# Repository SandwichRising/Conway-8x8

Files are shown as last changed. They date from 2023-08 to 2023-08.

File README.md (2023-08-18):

# Conway-8x8
8x8 Circuit Sculpture of Conway's Game of Life
conway front Conway Circuit Sculpture
conway back Conway Circuit Sculpture Backside
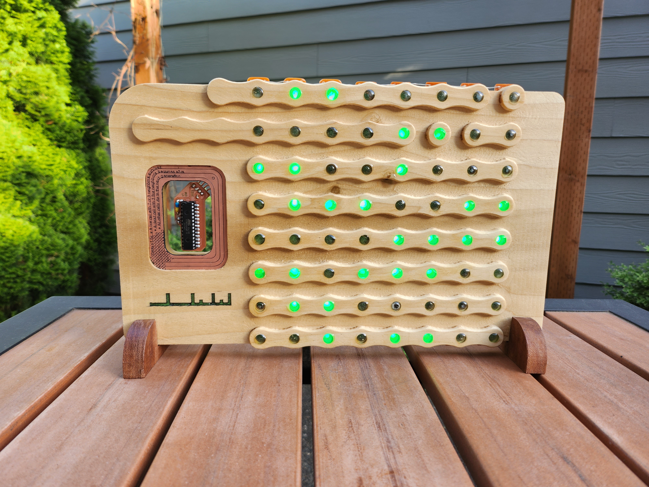
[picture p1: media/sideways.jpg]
conway sideways Conway Circuit Sculpture Sideways


   This project is the collection of files necessary to make the above pictured 8x8 grid sculpture playing out [Conway's Game of Life](https://www.youtube.com/watch?v=Kk2MH9O4pXY) on an ATmega 328P. This project spanned 3 separate periods: 110 hours were spent developing the original software and building a circuit sculpture for a [separate 6x6 design](./media/6x6_design.jpg) which maxed the CPU capabilities; 20 hours were spent doing a technical analysis, refactoring, and writeup of the created data structure to scale from 6x6 to larger sizes; 130 hours over 3 weeks were then spent developing this project into new physical hardware. 

   The 130-hour period is captured in this github. This time was spent integrating the new 8x8 software to match new hardware, conceptualizing the full physical design from scratch, modeling the wooden case in Fusion360, designing the circuit boards in KiCad, producing CNC gcode for the PCBs and case in Fusion360, cutting the wood and copper/fr4 circuit boards on an Onefinity CNC machine, treating the wood and creating epoxy lenses, soldering the circuits, as well as testing and improving the design while in-progress. The project was created to demonstrate hardware implementation of a data structure (from concept to physical object) for a classroom grade, as this process is much more complicated than a solely-software approach. Unfortunately, the project did not count for very much credit, however the entire process was quite therapeutic and educational, and I was very pleased with the results.

## What the Sculpture Does
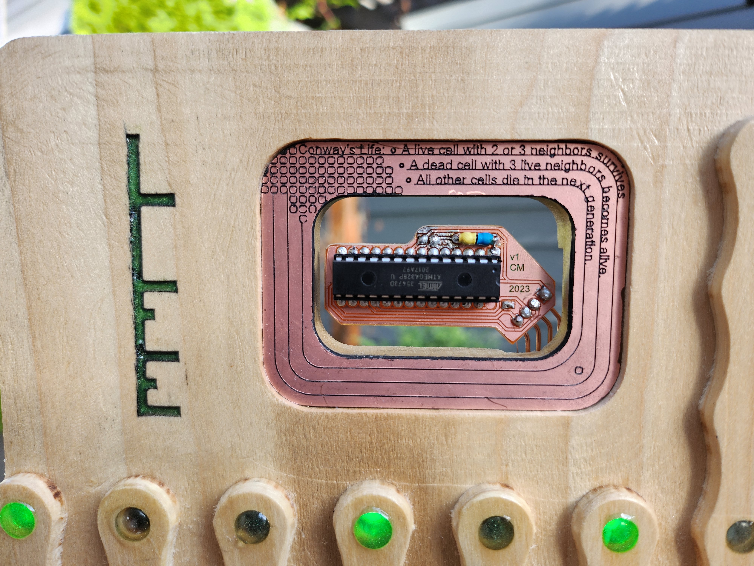
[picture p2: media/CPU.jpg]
brain PCB ATmega 328P CPU

   The sculpture creates a random gameboard using a floating microcontroller pin, and then applies Conway’s rules to evolve which cells live or die. The floating pin polls random energy in the air to seed the random number generator. The gameboard itself represents viewing one of an infinitely repeating 8x8 grid in every direction, as the top/bottom and left/right sides are considered ‘touching’ for the evolution process. Another way to visualize this is as a grid stretched over a [torus](https://en.wikipedia.org/wiki/Torus). This implementation remembers 48 board histories to check for duplicates, as a duplicate gameboard will always evolve along the same path (which traps the display into repeating itself forever). The bulk of the processor’s memory is used in saving these histories. If a duplicate gameboard is detected in history, the living cells flash out of existence in a specific way to let the observer know they ‘lived forever’, and a new random gameboard is generated. Otherwise, the game will continue to play out until all cells die out, and afterward a new board is generated. This 8x8 board has 68,719,476,736 unique starting conditions possible. 
  
  You can see the sculpture running in the video below. Unfortunately, the camera shutter speed clashes a bit with the FPS of the sculpture so the video footage doesn’t look as good as seeing it run in person. Lopsided ‘blinky’ math is used to transition cells on and off to make it easier for one's brain to track the groups of cells dying and coming alive each evolution cycle. The video was recorded while testing that the sculpture display matched what the software was providing, with an external Arduino streaming data to the display and the laptop simultaneously.
running display Display Running Test Program

   I enjoy seeing the display run from behind the sculpture, where the LEDs can be seen through the circuit boards.
running display from behind Display Running Viewed From Behind

## The Project’s Goals
   The intent of the project had two primary purposes: refactor the existing software data structure to be more efficient, and to develop new improved techniques for hardware creation to realize the data structure physically. In software, a technical analysis of the original 6x6 data structure was done and improvements were made to allow up to a 32x32 size (while still maintaining auto-reset features to detect if a repeating pattern emerged). Methods for further improvement were also discovered, but not yet implemented. After the software was improved, an 8x8 size for the hardware was chosen for timeline practicality. In hardware, the goals were to create working SMD circuits using a CNC process, integrating multiple of these PCBs together into a larger overall circuit, designing this circuit alongside a tailor-cut housing to host them, and to attempt using epoxy as an appealing LED lens.
   
   The software was developed in Arduino IDE v1.8.13. [The source code is provided here](./src/conway3/conway3.ino).

## The Build Log
  The rest of this readme is designed as a build log. The build process is documented below for anyone wishing to recreate this sculpture. STL files for all housing pieces are located [here](./models), KiCad files for the circuit are provided [here](./kicad/conway), and images of the different PCB traces for an etching process are provided [here](./pcb_svg_images). Creating/providing gcode is outside the scope of this writeup, as the process is highly dependent on the specific tools used to manufacture.
  
   The housing is made from poplar wood, a light wood with a subtle natural greenish tint. The feet (and failed trim) are made from sapele, a naturally red wood. The wood and PCBs were all sealed with a polyurethane spray for protection. The circuits are all cut from single-sided copper fr4 PCB blanks. The CPU is a standalone ATmega 328P (flashed as a standalone chip using it's internal oscillator), 10k resistor (with yellow/blue shrink, to pull the reset pin up to 5v), and 10uF capacitor (seen on the rear, required for power smoothing). The LED PCBs use [74HC595 shift registers]( https://www.digikey.com/en/products/detail/nexperia-usa-inc/74HC595D-118/763087), [470 Ohm resistor arrays](https://www.digikey.com/en/products/detail/bourns-inc/CAY16-471J4LF/2566756), and generic green 3V 20mA LEDs. A generic USB PCB was soldered to the GND and 5V lines of the bus PCB (the 328P chip used does not support USB data, so only power was connected).

After developing the software, the circuits were drawn in KiCad (v5.1.9) to find the practical sizes and shapes for the circuit boards.
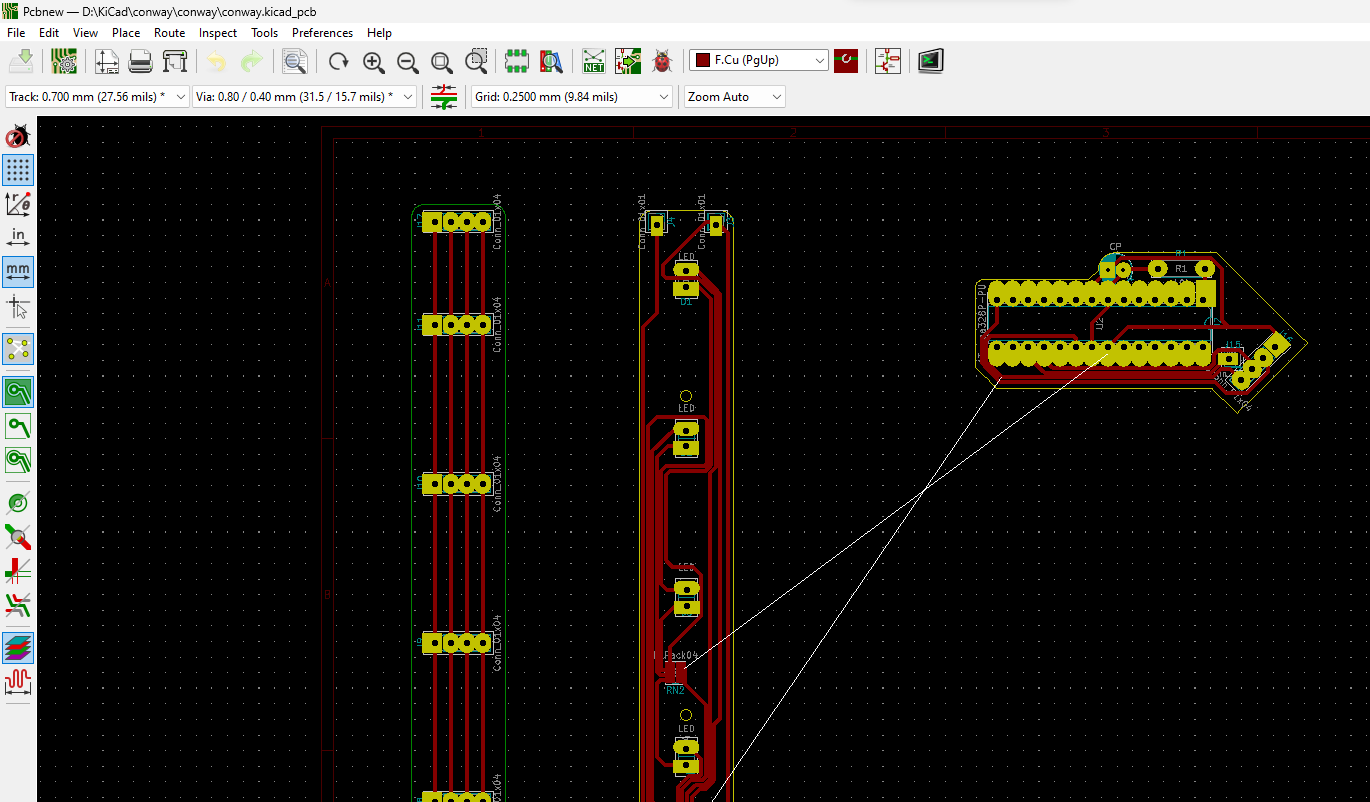
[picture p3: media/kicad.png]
kicad KiCad desktop view


Once the circuits were designed and sized, electronic components were ordered and the wooden housing was modeled in Fusion360. After modeling, machine cutpaths were assigned and exported as gcode in Fusion360 and the back of the housing was cut. Wooden pillars were used to place the wood stock precisely on the CNC bed, as the board would need flipped on the next step, and the pillars allowed for exact X and Y axis alignment. Before cutting, a small amount of polyurethane was sprayed where the text engraving would be to prevent paint overspray from absorbing into the wood. After cutting, this engraving area was taped off and sprayed with black spray paint. After drying, sanding the area removed the excess paint but left the engraved text painted.
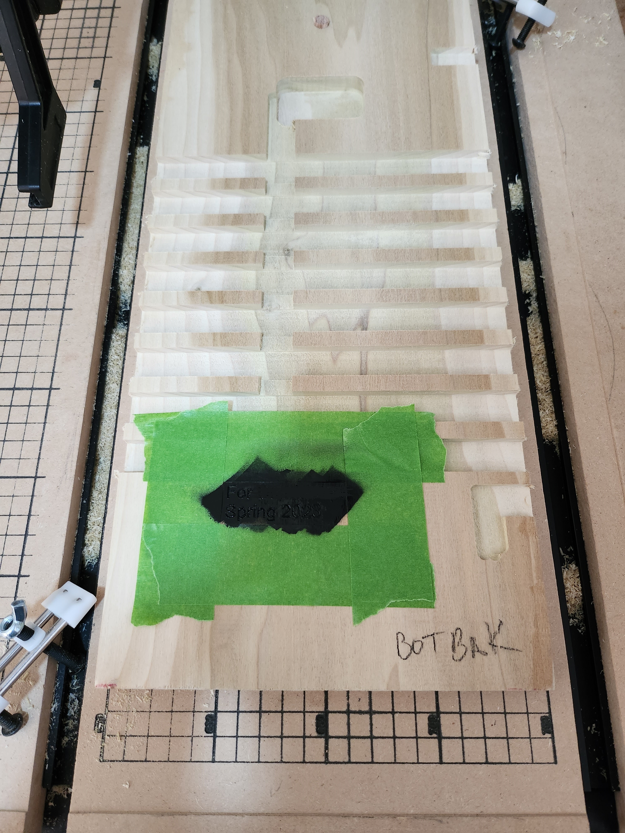
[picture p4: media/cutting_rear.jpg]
cutting rear housing Cutting Rear Housing


The wooden board was then flipped, aligned to the bed’s peg holes, and the front was then cut. The front used different woodworking bits to create the wavy pattern, cut away bulk material, engrave lettering, and drill LED holes. The same spray paint technique from before was used to fill the LIFE lettering with black paint (green epoxy was added later).
front housing Cutting Waves
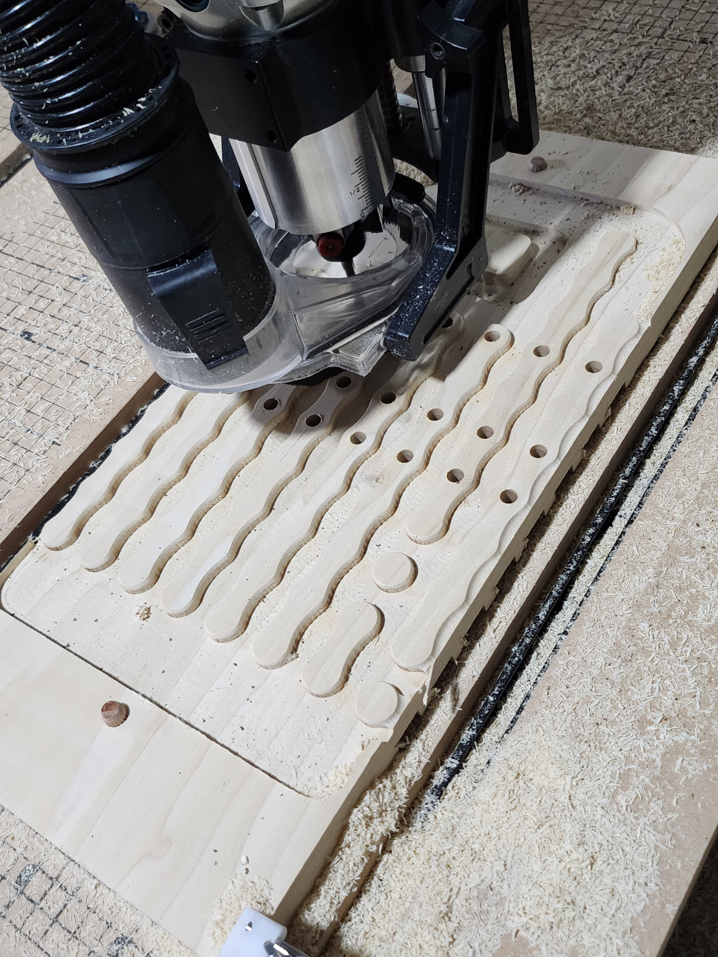
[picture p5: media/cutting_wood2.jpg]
front housing Cutting Holes

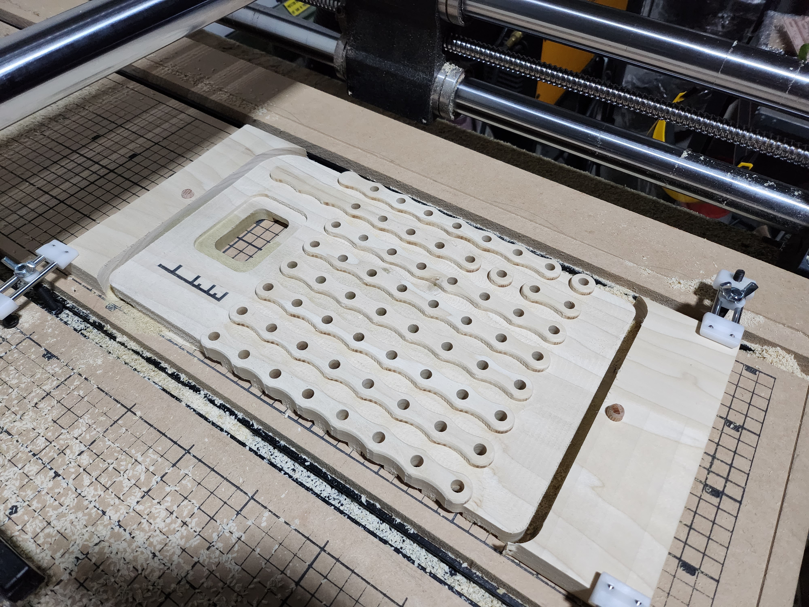
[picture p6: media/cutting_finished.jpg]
front housing Finished Cutting


A process with two different types of epoxy was used for the visibile lenses over the leds. First, clear tape was placed over the display face, covering the LED holes, and a small amount of 2-part green epoxy was poured into the holes from behind. After the epoxy had time to set, the tape was removed and a different UV epoxy was added in a droplet-shape to create a magnifying lens over the top, then hardened with a UV light into its round shape. This picture shows the piece of scrap wood to test the process. Only one of the 5 test pours pictured has the UV lens over the top.
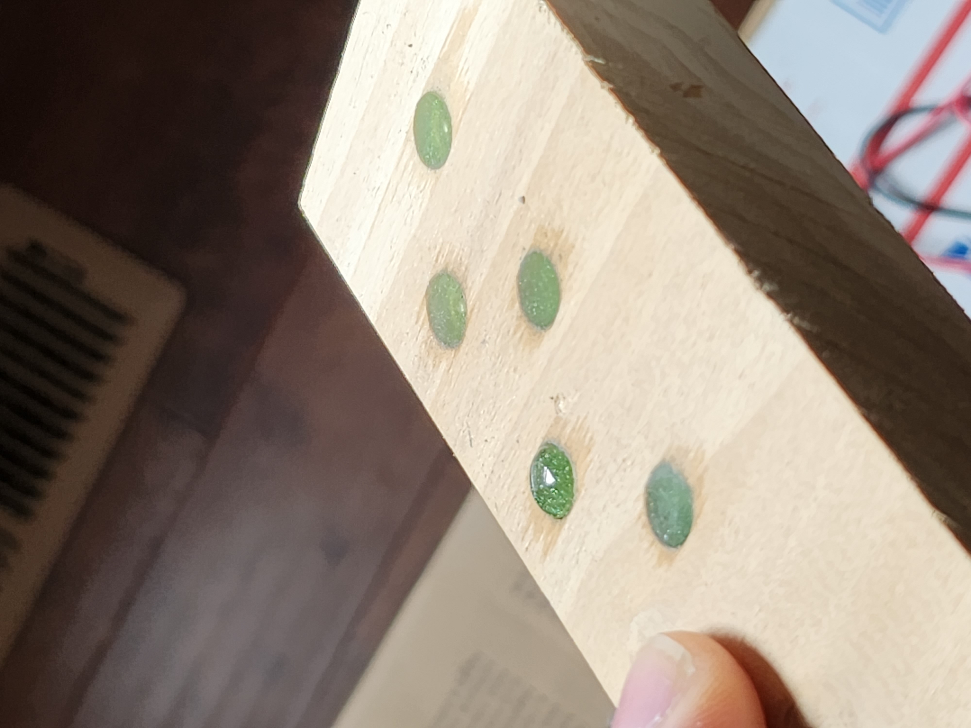
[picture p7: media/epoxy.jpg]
testing epoxy Epoxy Test


Additional trim was modeled and cut, with the plan to have more contrast in the design.
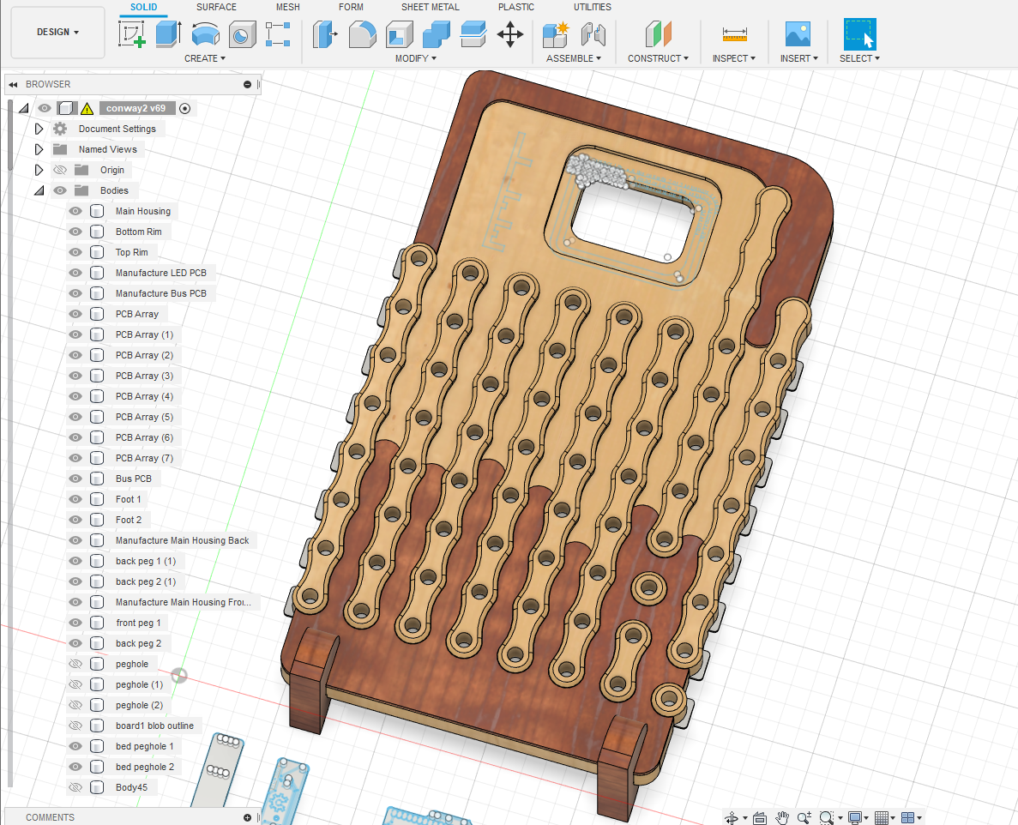
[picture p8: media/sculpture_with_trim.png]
trim design Trim Design

This did not work out as planned, though. The trim wood was cut to only be 3mm thick, but the board used was not perfectly flat and this resulted in a failed cut. Pre-processing the side of the board resting against the CNC machine bed flatter with a surfacing bit could have prevented this. There wasn’t enough sapele left in my shop to try again, so the contrasting trim idea was scrapped along with the failed cuts.  
trim failure Failed Trim Cut

Luckily, the section of sapele reserved for the feet was still usable, and this cut went well.
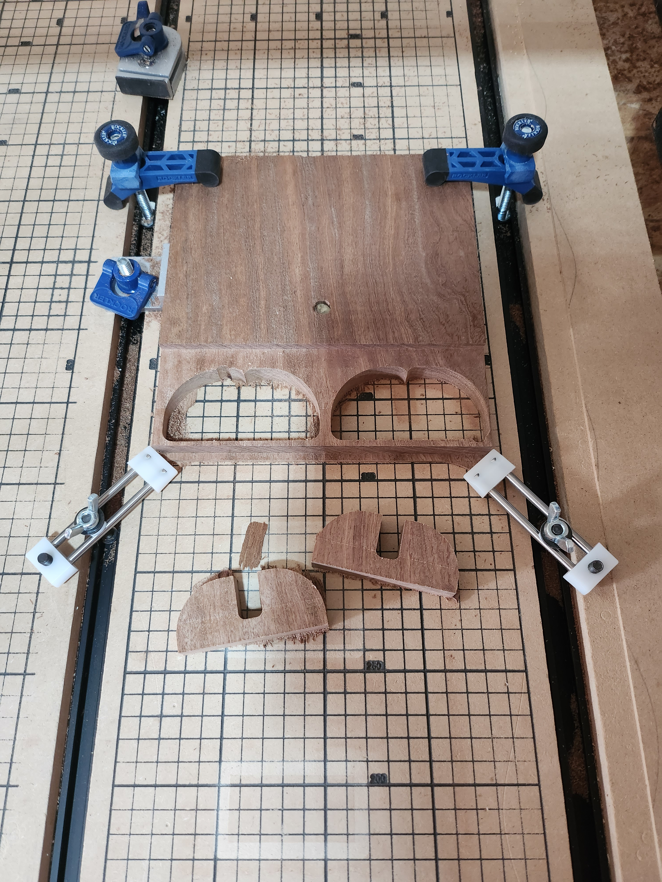
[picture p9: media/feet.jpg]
feet cutting Feet Cut


The LED PCBs were then cut on the CNC machine. The electrical traces are 0.7mm wide, and I had not cut this finely before. A total of 4 different styles of bits were used over multiple days before finding a 60-degree (inclusive) carbide bit that cut well at around 10k RPM, with some of the finer angled bits breaking in the process. More than 15 PCBs were cut, with 8 being usable in the end. You can see some of the progress from right to left in the picture.
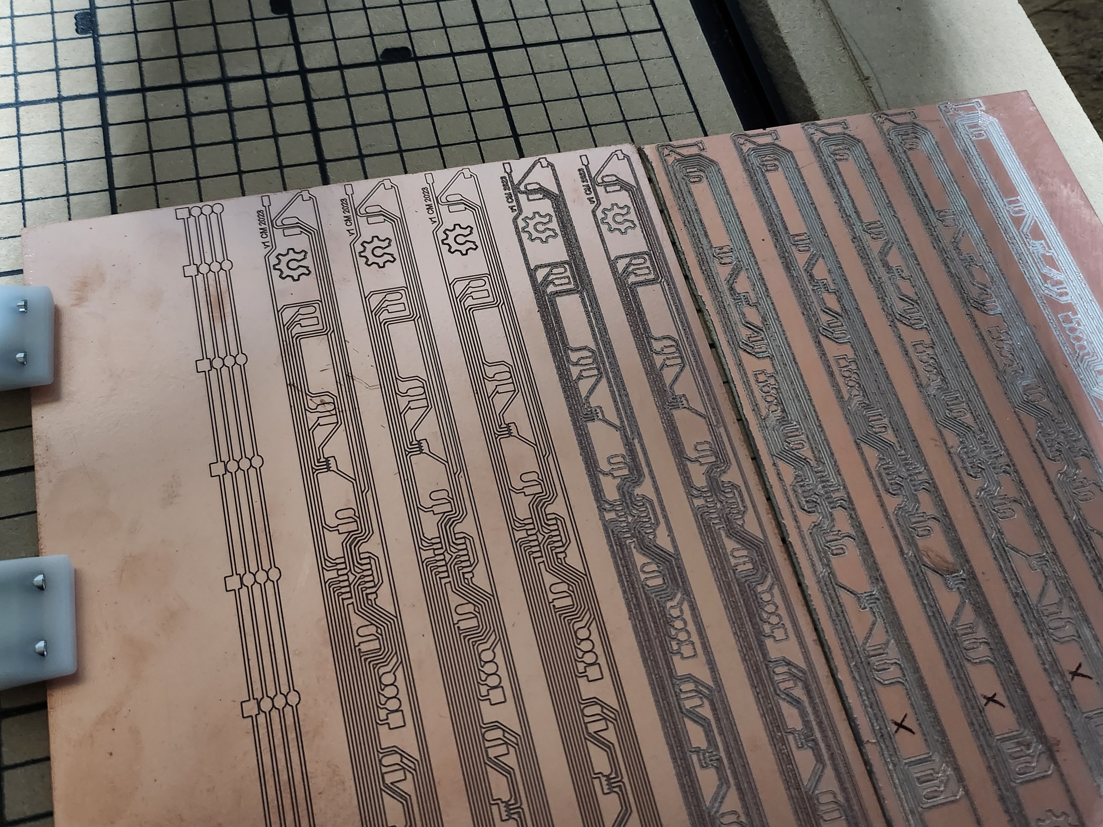
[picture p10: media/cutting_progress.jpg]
led pcb cuts LED PCB Cutting Progress


Each PCB was hand soldered using a syringe of lead-free low temperature solder on the SMD parts, and lead-free spooled solder on the through-hole parts. The soldering was done with a combination of hot air reflow and soldering iron work until all connections tested correctly with a multimeter. 
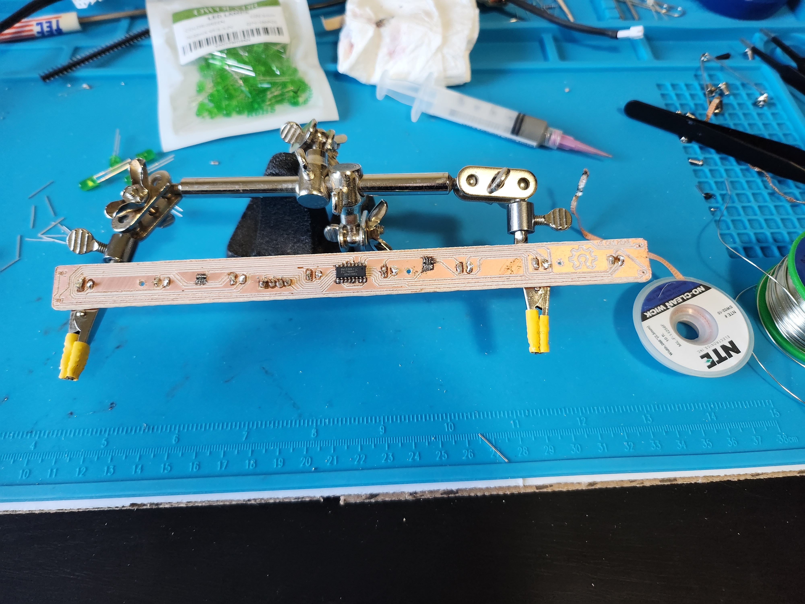
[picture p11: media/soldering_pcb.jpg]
led pcb soldering LED PCB Soldering


The LED PCBs were then assembled using the bus PCB to connect them all, and then brain PCB was attached using solid-core wire (to create a floating effect) and a thin data wire was run to the data-in of the first LED PCB. All the data-out/data-in ports on the LED PCBs were then connected using solid core wire along the side of the structure. The USB port was also connected to the bus PCB, but only 5v and GND were connected to the USB port. 
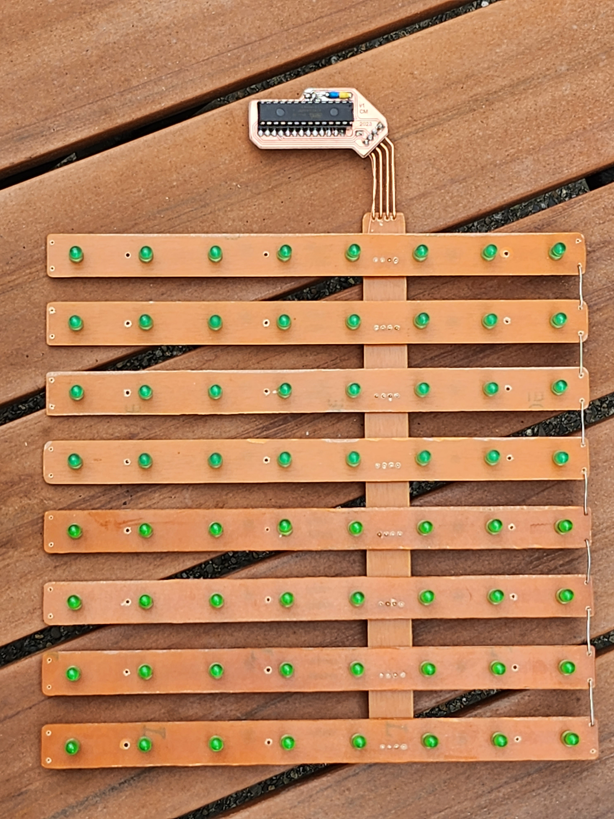
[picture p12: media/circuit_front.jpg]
completed circuit Complete Circuit

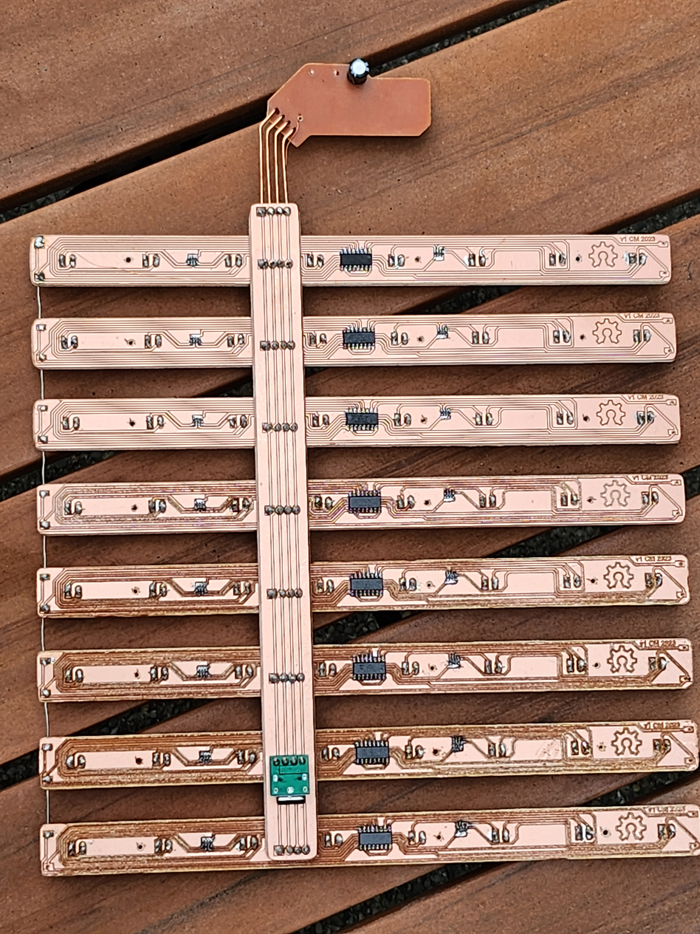
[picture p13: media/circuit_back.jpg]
completed circuit from behind Complete Circuit Back


The display was tested during assembly by streaming data from an Arduino UNO (with a 328P processor) using jumper wires, making sure the display matched up with what the software was outputting to the laptop over serial connection (shown in a video above). After the testing was verified and the circuit was fully assembled, the copper was sprayed with polyurethane to protect it from moisture.
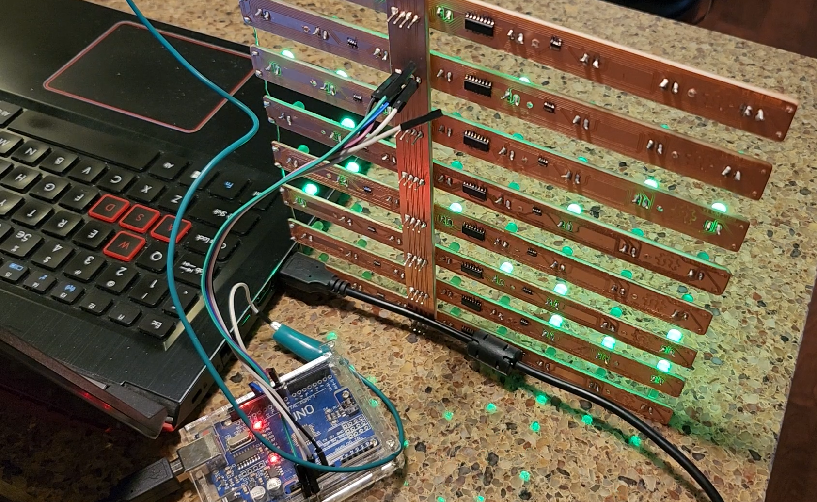
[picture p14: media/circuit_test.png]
testing the circuit Testing the Full Display


After all testing was done, a standalone 328P was flashed with the 8x8 program (using the internal oscillator instead of external clock) and the circuit was attached to the housing with screws. The view from the rear while its running is still my favorite.
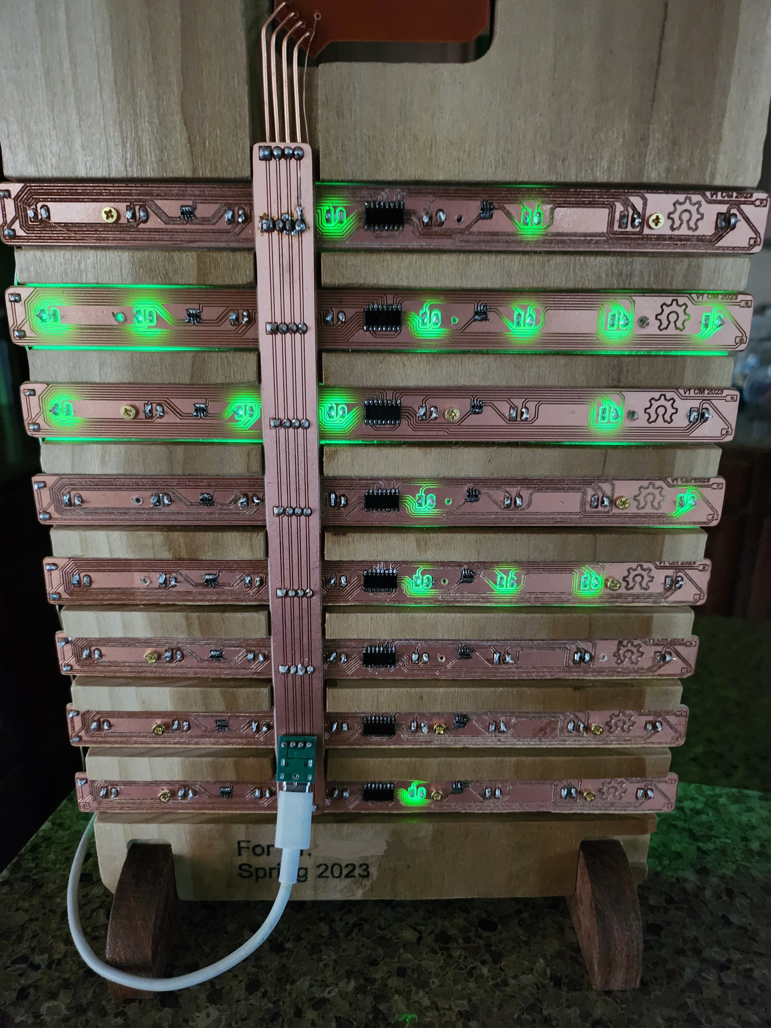
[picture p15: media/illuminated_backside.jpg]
circuit running and viewed from behind Viewing the Display from Behind


If you’ve made it this far, extra thanks for taking a look! If you make one, be sure to let me know!

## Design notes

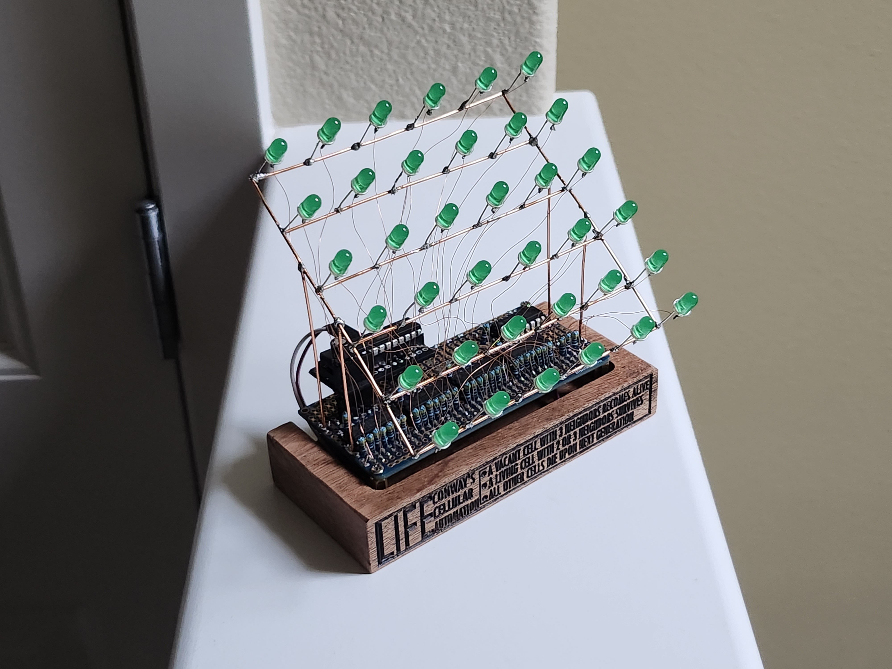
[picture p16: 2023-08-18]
media/6x6_design.jpg

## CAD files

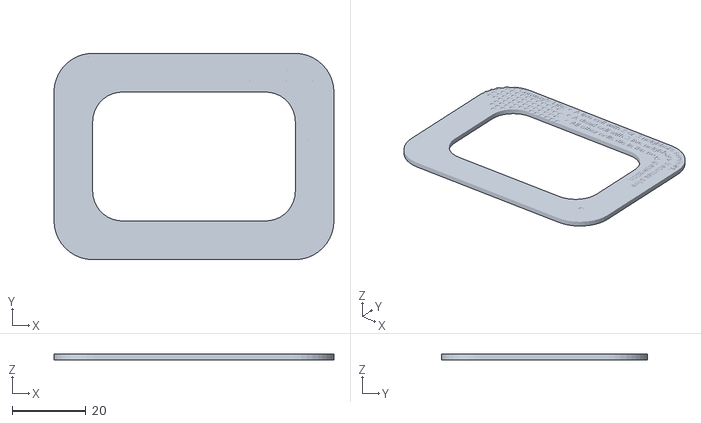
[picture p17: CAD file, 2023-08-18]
models/conway-8x8_decorative_plate.stl
76.0 x 56.0 x 1.50

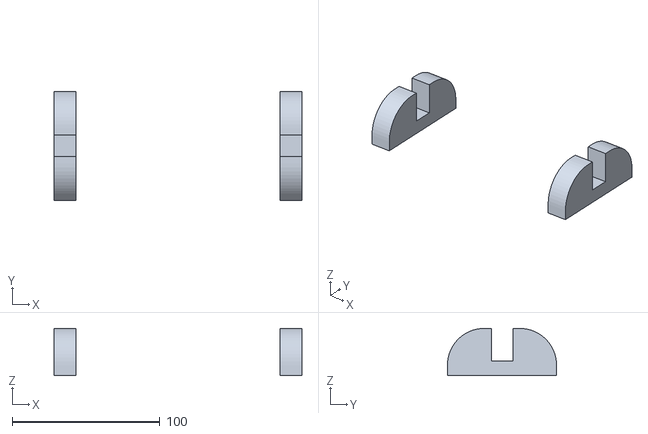
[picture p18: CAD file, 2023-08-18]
models/conway-8x8_feet.stl
168.0 x 74.0 x 32.0

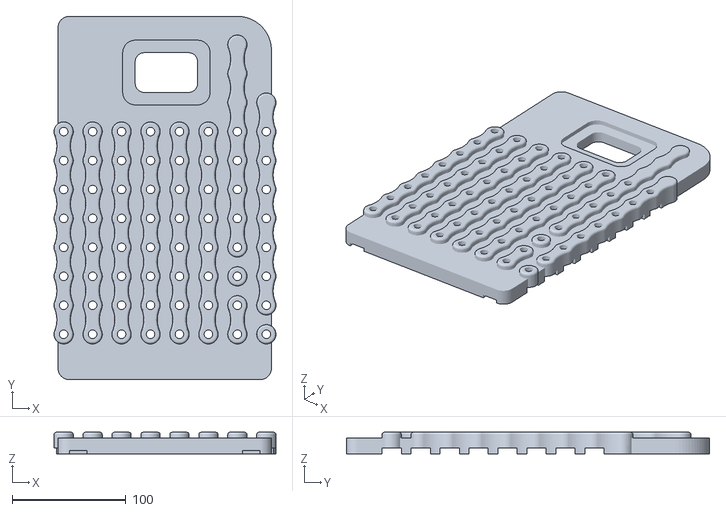
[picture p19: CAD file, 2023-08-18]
models/conway-8x8_housing.stl
195.5 x 320.0 x 19.0

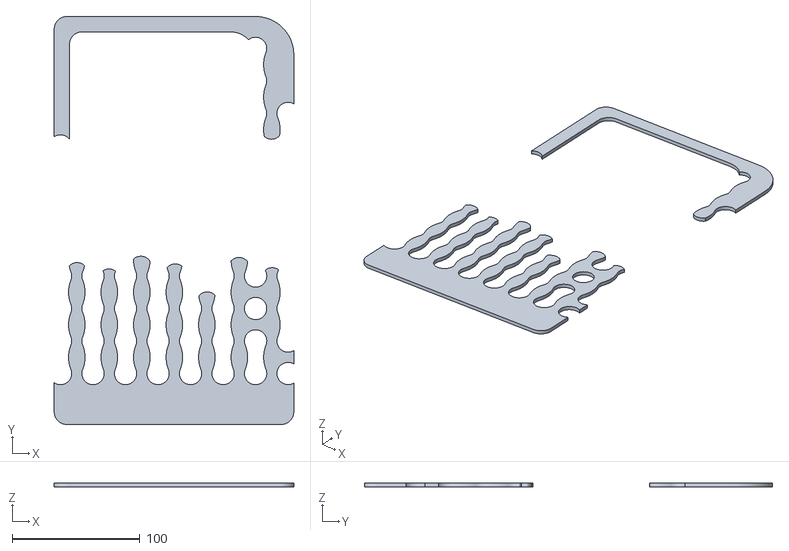
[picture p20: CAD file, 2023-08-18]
models/conway-8x8_decorative_trim.stl
188.0 x 320.0 x 3.00

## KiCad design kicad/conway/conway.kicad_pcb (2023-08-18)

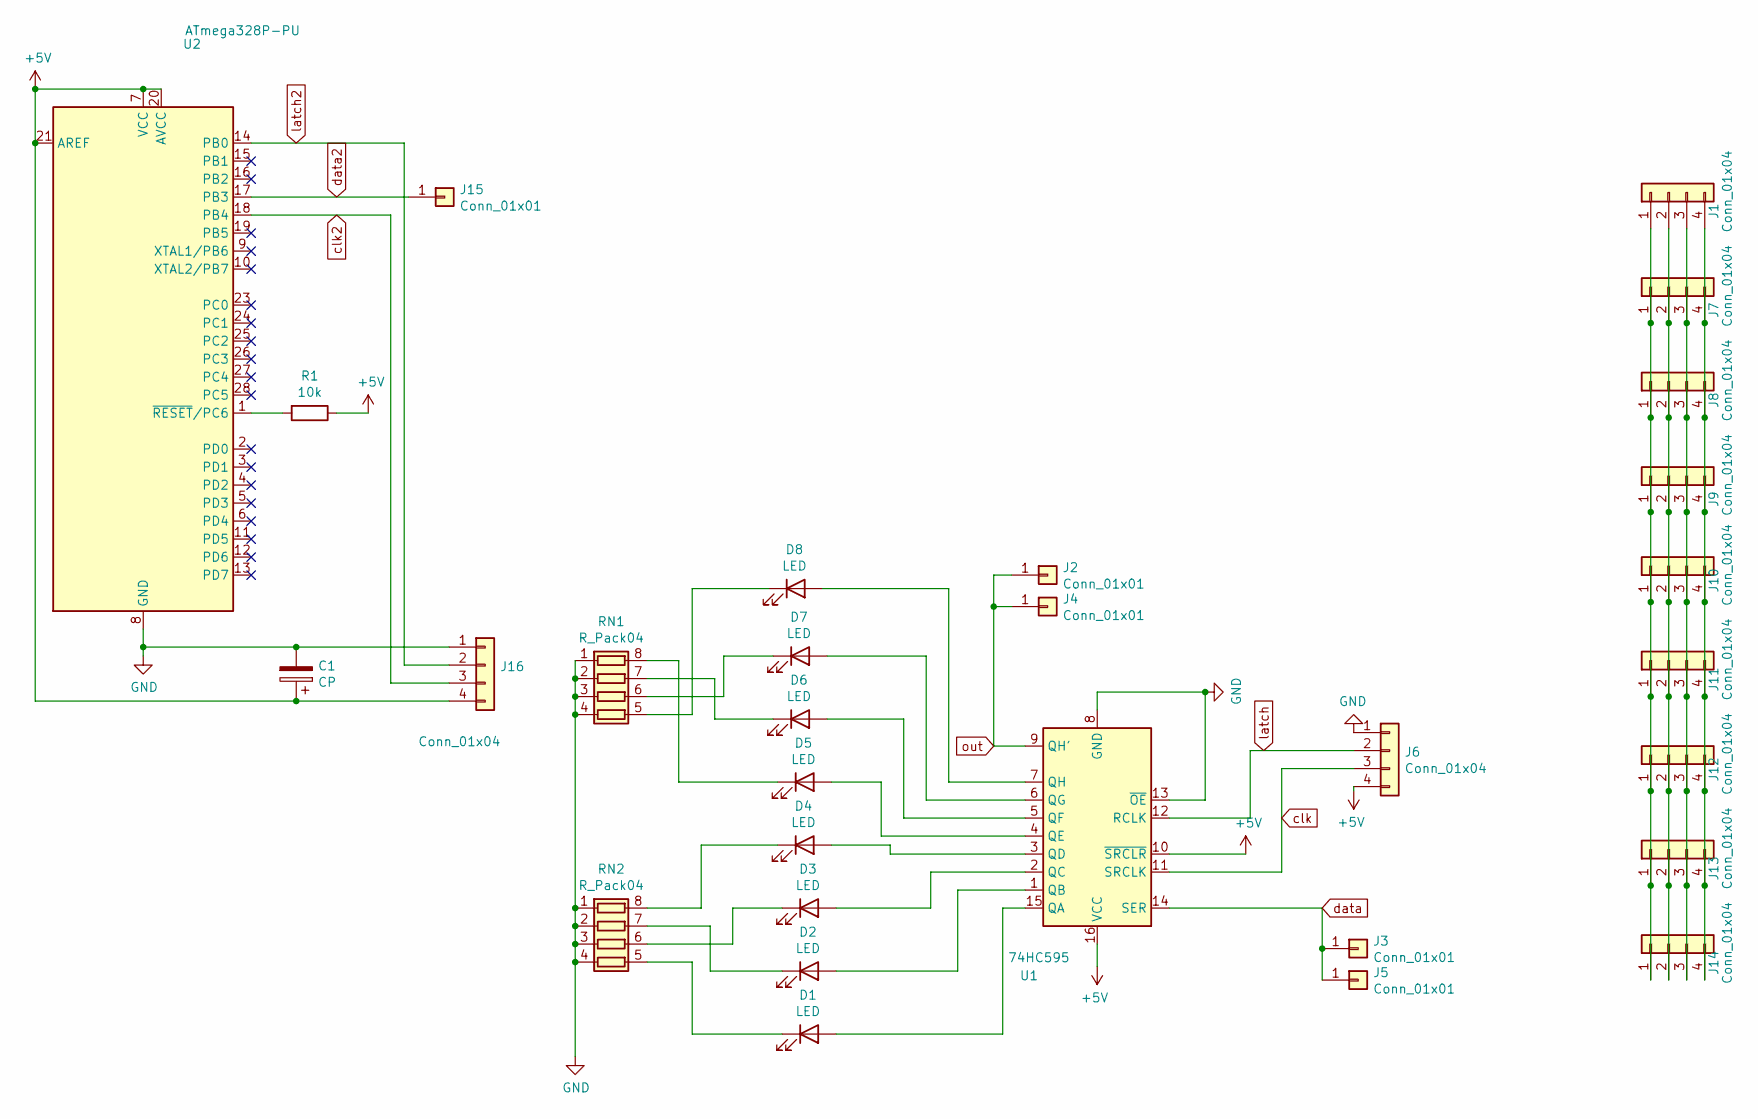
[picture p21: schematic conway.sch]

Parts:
C1: CP; CP_Radial_D5.0mm_P2.50mm_Custom_HandSolder
D1, D2, D3, D4, D5, D6, D7, D8: LED; PinHeader_1x02_P2.54mm_Vertical_Custom_Hand_Solder
J1, J6, J7, J8, J9, J10, J11, J12, J13, J14, J16: Conn_01x04; PinHeader_1x04_P2.54mm_Vertical_Custom_Hand_Solder
J2, J5, J15: Conn_01x01; PinHeader_1x01_P2.54mm_Vertical_Custom_Left_Hand_Solder
J3, J4: Conn_01x01; PinHeader_1x01_P2.54mm_Vertical_Custom_Right_Hand_Solder
R1: 10k; R_Axial_DIN0207_L6.3mm_D2.5mm_P7.62mm_Horizontal_Custom_Han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
RN1, RN2: R_Pack04; R_Array_Convex_4x0603_Custom_Hand_Solder
U1: 74HC595; SOIC-16_3.9x9.9mm_P1.27mm_Custom_Hand_Solder
U2: ATmega328P-PU; DIP-28_W7.62mm_Custom_HandSolder

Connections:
+5V: C1.1, J6.4, J16.4, R1.1, U1.10 (~SRCLR), U1.16 (VCC), U2.7 (VCC), U2.20 (AVCC), U2.21 (AREF)
GND: C1.2, J6.1, J16.1, RN1.1 (R1.1), RN1.2 (R2.1), RN1.3 (R3.1), RN1.4 (R4.1), RN2.1 (R1.1), RN2.2 (R2.1), RN2.3 (R3.1), RN2.4 (R4.1), U1.8 (GND), U1.13 (~OE), U2.8 (GND), U2.22 (GND)
unnamed: D1.1 (K), RN2.5 (R4.2)
unnamed: D1.2 (A), U1.15 (QA)
unnamed: D2.1 (K), RN2.7 (R2.2)
unnamed: D2.2 (A), U1.1 (QB)
unnamed: D3.1 (K), RN2.6 (R3.2)
unnamed: D3.2 (A), U1.2 (QC)
unnamed: D4.1 (K), RN2.8 (R1.2)
unnamed: D4.2 (A), U1.3 (QD)
unnamed: D5.1 (K), RN1.8 (R1.2)
unnamed: D5.2 (A), U1.4 (QE)
unnamed: D6.1 (K), RN1.7 (R2.2)
unnamed: D6.2 (A), U1.5 (QF)
unnamed: D7.1 (K), RN1.6 (R3.2)
unnamed: D7.2 (A), U1.6 (QG)
unnamed: D8.1 (K), RN1.5 (R4.2)
unnamed: D8.2 (A), U1.7 (QH)
unnamed: J1.1, J7.1, J8.1, J9.1, J10.1, J11.1, J12.1, J13.1, J14.1
unnamed: J1.2, J7.2, J8.2, J9.2, J10.2, J11.2, J12.2, J13.2, J14.2
unnamed: J1.3, J7.3, J8.3, J9.3, J10.3, J11.3, J12.3, J13.3, J14.3
unnamed: J1.4, J7.4, J8.4, J9.4, J10.4, J11.4, J12.4, J13.4, J14.4
unnamed: R1.2, U2.1 (~RESET~/PC6)
clk: J6.3, U1.11 (SRCLK)
clk2: J16.3, U2.18 (PB4)
data: J3.1, J5.1, U1.14 (SER)
data2: J15.1, U2.17 (PB3)
latch: J6.2, U1.12 (RCLK)
latch2: J16.2, U2.14 (PB0)
out: J2.1, J4.1, U1.9 (QH')

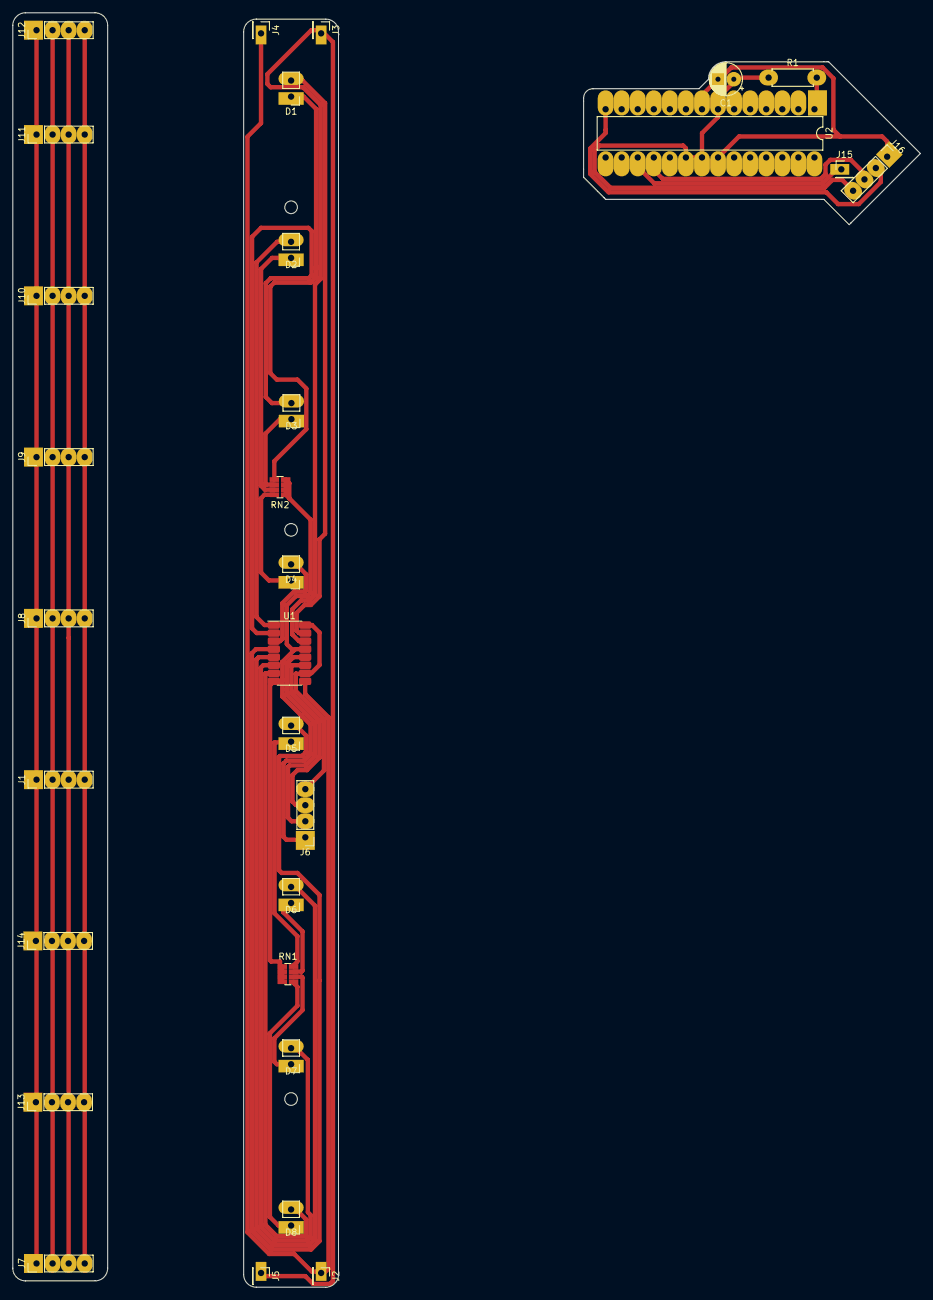
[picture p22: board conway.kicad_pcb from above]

Board: 2 copper layers, 143.5 x 201.5 mm, 30 parts (0 on the bottom side), 30 nets.

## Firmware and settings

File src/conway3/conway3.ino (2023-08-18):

// Conway's Game of Life 
// for circuit sculptures using shift registers
// version 3
// SandwichRising 2023


// game settings
const int columns = 8;        // how many columns of cells
const int cellsPerColumn = 8  ; // how many cells per column
int evolutionDelay = 3000; // delay in ms between cycles
const int percentChanceCell = 35; // desired percent of the board to get living cells on random roll
const int historyMax = 48;  // qty of gameboard histories to save

// hardware settings
const int PIN_DATA = 11; // using SPI port to increase transmit speed
const int PIN_CLOCK = 12; // using SPI port to increase transmit speed
const int PIN_LATCH = 8;
const int PIN_RANDOMSEED = A5; // unused analog pin left floating to generate seed on powerup
const int qty595 = 8; //how many 595 chips in use //Math.ceil((columns*cellsPerColumn)/8);
// options pins - physical switches may be added to these pins to set different modes if connected to GND
const int PIN_OPTION1 = A0;  // adds 1500ms to evolutionDelay
const int PIN_OPTION2 = A1;  // glider mode - lowers history count to preserve gliders
const int PIN_OPTION3 = A2;  // suppress data out (for demonstrating serial comms to the display manually) 
const int PIN_OPTION4 = A3;  // test leds
byte optionsContainer[4] = {0,0,0,0}; // (1)slow-mode, (2)suppress glitch, (3)suppress data out, (4)test leds



// hardware/software global variables

// GAME BOARD - 1d array of bytes to represent 2d grid
const int bytesPerGrid = (((columns * cellsPerColumn)/8) + 1);
byte grid[bytesPerGrid] = {0}; //{0x0F, 0xF0, 0xFF, 0xAA, 0x55, 0xFF, 0xF0, 0x0F}; // test pattern loaded into initial gameboard
byte tempgrid[bytesPerGrid] = {0}; // temp container to store next evolution without editing current
byte gridHistory[historyMax][bytesPerGrid];

// leds
int ledIntensity[columns][cellsPerColumn]; // tracks relative brightness of each led
int ledAdjuster[columns][cellsPerColumn];  // used to modify ledIntensity
int ledMax = 9; // 9 = smooth. higher numbers (99) can provide glitching effect to transitions
int intensitySteps = 55;   // ms between changing intensity levels
byte ledContainer[qty595]; // stores 8 bits of the board at a time to shiftOut()
const byte blankContainer[5] = {0,0,0,0,0};
const int ledMin = 0;

// timers
unsigned int currentMillis = 0;
unsigned int evolutionTimer = 0;
unsigned int displayTimer = 0;
unsigned int intensityTimer = 0;
unsigned int runTimer = 0;
bool runCalculator = false;
bool blankTemp = true;
int frameCounter = 1;

#define NORMAL 0
#define GLITCHY 1

// debug vars
unsigned int debugTimer = 0;
unsigned long cps = 0; // program cycles per second


// GAME BOARD/HISTORY HELPER FUNCTIONS
boolean readGrid(int row, int rowIndex) {  // reads out grid y x as bool, zero indexed

  //convert 2d request into 1d array of bytes bitshifted to have request placed on MSB
  byte examine = grid[(((row * cellsPerColumn) + rowIndex) / 8)]; //extract byte containing cell
  examine = examine << 7 - (((row * cellsPerColumn) + rowIndex) % 8);  //move bit to MSB
  return (examine >> 7); //return MSB bit as bool
  
}

void writeGrid(int row, int rowIndex, bool writeValue) {  // writes to grid, zero indexed

  //convert 2d request into 1d array of bytes to set or clear a location
  if (writeValue) bitSet(grid[(((row * cellsPerColumn) + rowIndex) / 8)], (((row * cellsPerColumn) + rowIndex) % 8));
  else bitClear(grid[(((row * cellsPerColumn) + rowIndex) / 8)], (((row * cellsPerColumn) + rowIndex) % 8));
}

boolean readTemp(int row, int rowIndex) {  // reads grid, zero indexed

  //convert 2d request into 1d array of bytes bitshifted to have request placed on MSB
  byte examine = tempgrid[(((row * cellsPerColumn) + rowIndex) / 8)]; //extract byte containing cell
  examine = examine << 7 - (((row * cellsPerColumn) + rowIndex) % 8);  //move bit to MSB
  return (examine >> 7); //return MSB bit as bool
}

void writeTemp(int row, int rowIndex, bool writeValue) {  // writes to grid, zero indexed

  //convert 2d request into 1d array of bytes and sets or clears location
  if (writeValue) bitSet(tempgrid[(((row * cellsPerColumn) + rowIndex) / 8)], (((row * cellsPerColumn) + rowIndex) % 8));
  else bitClear(tempgrid[(((row * cellsPerColumn) + rowIndex) / 8)], (((row * cellsPerColumn) + rowIndex) % 8));
}

boolean readHistory(int histNum, int row, int rowIndex) {  // reads out grid y x as bool, zero indexed

  //convert 2d request into 1d array of bytes bitshifted to have request placed on MSB
  byte examine = gridHistory[histNum][(((row * cellsPerColumn) + rowIndex) / 8)]; //extract byte containing cell
  examine = examine << 7 - (((row * cellsPerColumn) + rowIndex) % 8);  //move bit to MSB
  return (examine >> 7); //return MSB bit as bool
  
}


void writeHistory(int histNum, int row, int rowIndex, bool writeValue) {  // writes single bit to history grid, zero indexed

  //convert 2d request into 1d array of bytes and set or clear
  if (writeValue) bitSet(gridHistory[histNum][(((row * cellsPerColumn) + rowIndex) / 8)], (((row * cellsPerColumn) + rowIndex) % 8));
  else bitClear(gridHistory[histNum][(((row * cellsPerColumn) + rowIndex) / 8)], (((row * cellsPerColumn) + rowIndex) % 8));
}


void writeHistoryBytes(int histNum, bool gridCopy) {  //grid copy TRUE = copy from grid, FALSE = copy from previous history

  for (int i = 0; i < bytesPerGrid; i++) {

    if (gridCopy) gridHistory[histNum][i] = grid[i];
    else gridHistory[histNum][i] = gridHistory[histNum + 1][i]; 
  }
}



// SETUP
void setup() {

  // debug - used to display gameboard and debug info over serial
  //Serial.begin(9600);

  // re-seed rng
  randomSeed(generateSeedNumber());

  // initialize output pins
  int outputPins[] = {PIN_DATA, PIN_CLOCK, PIN_LATCH};
  for (int i = 0; i < sizeof(outputPins); i++) {
    pinMode(outputPins[i], OUTPUT);
    digitalWrite(outputPins[i], LOW);
  } 
  // initialize input pins and detect options settings
  int inputPins[] = {PIN_OPTION1, PIN_OPTION2, PIN_OPTION3, PIN_OPTION4};
  for (int i = 0; i < sizeof(inputPins); i++) {
    pinMode(inputPins[i], INPUT_PULLUP);
    optionsContainer[i] = !digitalRead(inputPins[i]);
  } 
  if (optionsContainer[0]) evolutionDelay += 1500;

  //debug test screen - set screen to flash using software instead of physical switch
  //optionsContainer[3] = 1;
  
  fillGameBoard(false);
  fillLedsBlank();
  fillGameBoardHistory();
  
}


// LOOP
void loop() {

  currentMillis = millis();

  cycleEvolution();

  displayGameBoard();

  //displayDebug();

}




// setup functions

unsigned long generateSeedNumber() {
  unsigned long seedNumber = 0;
  for (int i = 0; i < 32; i++) {
    seedNumber = seedNumber << 1;
    bitWrite(seedNumber, 0, bitRead(analogRead(PIN_RANDOMSEED), 0));
  }
  return seedNumber;
}

void fillGameBoard(bool input) {

  for (int i = 0; i < columns; i++) {
    for (int j = 0; j < cellsPerColumn; j++) {
        //gameBoard[i][j] = input;
        writeGrid(i, j, input);
        ledAdjuster[i][j] = (input) ? 1 : -1;
    }
  }
  displayGameBoard();
}


void fillLedsBlank() {

  for (int i = columns - 1; i >= 0; i--) {
    for (int j = cellsPerColumn - 1; j >= 0; j--) {
        ledAdjuster[i][j] = 0;
        ledIntensity[i][j] = 0;
    }
  }
  displayGameBoard();
}

void fillGameBoardHistory() {
  
  for (int h = 0; h < historyMax; h++) {
    for (int i = 0; i < columns; i++) {
      for (int j = 0; j < cellsPerColumn; j++) {
        writeHistory(h,i,j,0);
      }
    }
  }
}



// loop functions

// applies Conway ruleset to gameBoard
void cycleEvolution(){
  
    // FIXME - code still running using inefficient boolean tempContainer instead of efficient tempgrid usage
   bool tempContainer[columns][cellsPerColumn];
    
    if((currentMillis - runTimer > 500) && runCalculator) { // half second delay between runs, along with flag
      
      if (checkAndUpdateBoardHistory()) {  // board history (and blank board) check
        
        // If check passes, perform Evolution Cycle
  
        glowStyle(NORMAL);
  
        const int neighborOffset[8][2] = {{-1,-1},{-1,0},{-1,1},{0,-1},{0,1},{1,-1},{1,0},{1,1}}; // x,y locations to check
        
        // cycle thru all locations to count how many neighbors each one has, then update cells
        for (int currentColumn = 0; currentColumn < columns; currentColumn++) {
          for (int currentCell = 0; currentCell < cellsPerColumn; currentCell++) {
  
            int totalNeighbors = 0;
  
            for (int neighborCycler = 0; neighborCycler < 8; neighborCycler++) {
  
              // set up column index number to check cell
              int columnIndex = currentColumn + neighborOffset[neighborCycler][0];
              // make sure the index is valid and didn't rollover
              if (columnIndex < 0) columnIndex += columns;
              else if (columnIndex >= columns) columnIndex -= columns;
  
              int cellIndex = currentCell + neighborOffset[neighborCycler][1];
              if (cellIndex < 0) cellIndex += cellsPerColumn;
              else if (cellIndex >= cellsPerColumn) cellIndex -= cellsPerColumn;
  
              // check if location alive, increment neighbor counter
              if (readGrid(columnIndex, cellIndex)) totalNeighbors += 1;
            }
  
  
  
            // if cell's location is alive....
            if (readGrid(currentColumn, currentCell)) {
  
              // if underpopulated or overpopulated, mark cell dead, otherwise mark alive
              if (totalNeighbors < 2 || totalNeighbors > 3) {
                tempContainer[currentColumn][currentCell] = false;
                //writeTemp(currentColumn,currentCell,false);
              }
              else tempContainer[currentColumn][currentCell] = true;
              //else writeTemp(currentColumn,currentCell,true);
  
            // else if cell location started dead....
            } else {
              
              // if exacty 3 neighbors are alive, come alive
              if (totalNeighbors == 3) tempContainer[currentColumn][currentCell] = true;
              //if (totalNeighbors == 3) writeTemp(currentColumn,currentCell,true);
            }
          }
        }
  
      runCalculator = false;  // prevent running evolution again until after board updates 
      runTimer = currentMillis;
  
      }
    }

    if (blankTemp) {
      for (int i = 0; i < columns; i++) {
        for (int j = 0; j < cellsPerColumn; j++) {
          tempContainer[i][j] = false;
        }
      }
      blankTemp = false;
    }

    
    
    if (currentMillis - evolutionTimer > evolutionDelay) {  // timer check

      evolutionTimer = currentMillis;  // timer update

      if (!isBlankBoard()){
        for (int i = 0; i < columns; i++) {
          for (int j = 0; j < cellsPerColumn; j++) {
  
            // fill gameboard with new data
            writeGrid(i, j, tempContainer[i][j]);
            // fill led adjuster to match
            ledAdjuster[i][j] = (tempContainer[i][j]) ? 1 : -1;
            //ledAdjuster[i][j] = (readTemp(i,j)) ? 1 : -1;
            
          }
        }
      } else randomizeGameBoard();
      
      //debug
      //displayDebug();       //display debug info over serial
      //printGameBoard();   //display gameboard over serial connection
      //printLedAdjuster(); //more debug serial info
      //printLedIntensity(); //more debug serial info

      runCalculator = true;
    }
    
}


// handles empty gameBoards, as well as gameboards with gliders and history repeats
bool checkAndUpdateBoardHistory(){

  bool proceedNormallyFlag = true;
  
  // if no cells are alive, regenerate random board
  if (isBlankBoard()) {
    
    proceedNormallyFlag = false;

  // else if there are populated cells...
  } else {
  
    // detect if current gameBoard has appeared in gameBoardHistory
    // bump items in the history back one history index
    // add gameBoard to the gameBoardHistory
    // h index 0 unused to keep incrementers in bounds

    int checkLength = historyMax;
    if (optionsContainer[1]) checkLength = 8; // option2 - preserve gliders by allowing patterns of +8

    for (int h = 1; h < checkLength; h++) {

      displayGameBoard();  // helps prevent some studder by displaying during calculations

      bool resetFlag = true;
      
      for (int i = 0; i < columns; i++) {
        for (int j = 0; j < cellsPerColumn; j++) {
          // check for difference in gameBoard vs history
          if (readGrid(i, j) != readHistory(h,i,j)) {
            resetFlag = false;
          }

          // bump history
          writeHistory((h-1),i,j,readHistory(h,i,j));
          // put gameboard in history
          if (h == (checkLength - 1)) writeHistory(h,i,j,readGrid(i,j));
        }
      }
      
      
      if (resetFlag) { 
        blankTemp = true;
        glowStyle(GLITCHY);
        proceedNormallyFlag = false;
      } 
    }
  }
  return proceedNormallyFlag;
}


// returns true if gameBoard is completely empty
bool isBlankBoard() { 

  for (int i = 0; i < columns; i++) {
    for (int j = 0; j < cellsPerColumn; j++) {
      //if (gameBoard[i][j] != false) return false;
      if (readGrid(i,j) != false) return false;
    }
  }
  return true;

}


// refill gameboard and ledAdjuster with randomly generated cells
void randomizeGameBoard() {

  for (int i = 0; i < columns; i++) {
    for (int j = 0; j < cellsPerColumn; j++) {

      //refill gameboard with random values (or ALL ON if option4 is selected)
      if (optionsContainer[3] == false) {
        writeGrid(i,j,((random(0,99) < percentChanceCell) ? true : false));
      } else  writeGrid(i,j,true);
      
      // fill led adjuster to match
      ledAdjuster[i][j] = (readGrid(i,j)) ? 1 : -1;

    }
  }
  
  glowStyle(GLITCHY);
}


// changes the way leds dim and glow, normalizes every evolutionCycle timer
void glowStyle(int stylePicker) {

  int switcher = stylePicker;
  // suppress glitch when using option4 (suppress glitch, and all leds on)
  if (optionsContainer[3]) switcher = 0;

  switch (switcher) {

    // normal
    case 0:
      ledMax = 9;
      intensitySteps = 55;
      break;

    // glitchy
    case 1: 
      ledMax = 99; // cause glitch effect
      intensitySteps = 5; // lower step delay to compensate for new ledMax
      increaseLedIntensity(); // increase brightness of already-on leds to compensate for new ledMax
      break;
  }
}

// helper for displaying glitch glow effects
void increaseLedIntensity(){

  for (int i = 0; i < columns; i++) {
    for (int j = 0; j < cellsPerColumn; j++) {
      if (ledIntensity[i][j] > 0) ledIntensity[i][j] = (ledMax / 2);
    }
  }

}


// translates ledIntensity array into ledContainer, then shiftOut()s the ledContainer
void displayGameBoard() {

  /* Fast Method Using SPI Bus
     This function is run in loop() without timers in order to rerun as quickly
     as possibile, causing the serial data stream out to the 595 chips to be the 
     bottleneck of the program. This allows as fast a display pf fps as possible,
     in order to simulate asyncronus dimming and brightening of leds.
  */

  incrementIntensity();
  
  //prep unused 595 locations in ledContainer (for gameboard sizes that aren't divisible by 8)
  int unused595pins = (columns*cellsPerColumn) % 8;
  for (int i = 0; i < unused595pins; i++) fillLedContainerBit(i, 0);

  // fill display (byte) containers to send to shiftOut() -> 595's 
  for (int i = 0; i < columns; i++) {
    for (int j = 0; j < cellsPerColumn; j++) {
      
      // convert row and cell number to overall led number
      //int ledNumber = ((columns*cellsPerColumn) - ((i*cellsPerColumn) + j)-1);
      int ledNumber = ((i*cellsPerColumn) + j);

      bool fillBit = false;

      // fills ledContainers using ledIntensity-based probability
      if (frameCounter % (ledMax + 1) < ledIntensity[i][j] && ledIntensity[i][j] > 0) {
        
        // applies dimmer to brighter leds. saves ~%50 power and only lowers perceived brightness a little
        if (frameCounter % 2 == 0 && (frameCounter % 10 > 4 || ledIntensity[i][j] > 7)) {;} //ledIntensity[i][j] > 7) {;}  // % 1: normal    % 2: half overall brightness
        
        //FIXME dimmer currently unused, no power savings
        //else fillBit = true; 
        fillBit = true; 
      }
      //fillLedContainerBit(ledNumber + unused595pins, fillBit);
      fillLedContainerBit(ledNumber, fillBit);
    }
  }
  

  if (optionsContainer[2] == false) {  // if DATA OUT isn't being suppressed by option3
    
    setLatch(LOW);  // allow 595's to fill register
    
      for (int i = 0; i < qty595; i++) {
        // shift out prepared ledContainer
        shiftOut(PIN_DATA, PIN_CLOCK, MSBFIRST, ledContainer[qty595 - i - 1]);
      }
    
    frameCounter++;
    if (frameCounter >= evolutionDelay) frameCounter = 1; // prevent rollover to zero
    setLatch(HIGH);  // latch the 595's to display register contents
  }
  
}


// adjusts ledIntensity using ledAdjuster to track how bright each led should be 
void incrementIntensity() {

  if (currentMillis - intensityTimer > intensitySteps) {

    for (int i = 0; i < columns; i++) {

      for (int j = 0; j < cellsPerColumn; j++) {

          // adjust intensity and stop adjustment when limits are reached
          ledIntensity[i][j] += ledAdjuster[i][j];
          if (ledIntensity[i][j] == ledMax || ledIntensity[i][j] == ledMin) ledAdjuster[i][j] = ledMin;
          
          //rollover protection
          else if (ledIntensity[i][j] > ledMax) {
            ledIntensity[i][j] = ledMax;

          //rollover protection
          } else if (ledIntensity[i][j] < ledMin) {
            ledIntensity[i][j] = ledMin;
          }
      }
    }
    intensityTimer = currentMillis;

  }

}


// fills given ledContainer bit with given bit
void fillLedContainerBit(int ledNumber, bool fillBit) {

    int index1 = (floor)(ledNumber/8);
    int index2 = ledNumber % 8;    
    bitWrite(ledContainer[index1], index2, fillBit);

}

// sets latch pin high or low
void setLatch(bool setting) {

  digitalWrite(PIN_LATCH, setting);

}



// Debug functions
void displayDebug() {

  cps++;

  if (currentMillis - debugTimer > 1000) {

    Serial.print("CPS: ");
    Serial.println(cps);
    debugTimer = currentMillis;
    cps = 0;

  }
}

void printGameBoard() {

    Serial.println();

    for (int i = 0; i < columns; i++) {

      for (int j = 0; j < cellsPerColumn; j++) {

        //if (gameBoard[i][j]) Serial.print('X');
        if (readGrid(i,j)) Serial.print('X');
        else Serial.print('_');
      }

      Serial.println();
    }
    
    Serial.println();

}

void printLedAdjuster() {

    Serial.println();

    for (int i = 0; i < columns; i++) {

      for (int j = 0; j < cellsPerColumn; j++) {

          Serial.print(ledAdjuster[i][j]);
      }

      Serial.println();
    }
    
    Serial.println();

}

void printLedIntensity() {

    Serial.println();

    for (int i = 0; i < columns; i++) {

      for (int j = 0; j < cellsPerColumn; j++) {

          Serial.print(ledIntensity[i][j]);
      }

      Serial.println();
    }
    
    Serial.println();

}
